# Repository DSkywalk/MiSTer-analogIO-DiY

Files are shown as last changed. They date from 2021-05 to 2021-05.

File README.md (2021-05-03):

# MiSTer-analogIO-DiY

The aim of this repository is to share boards that can be easily crafted at home (ex. Electric iron) for MiSTer FPGA enthusiasts. No SMD and trying to use almost one layer...

Of course, you can order these boards from OSHPark or any other PCB printing company, but that is not the main purpose of this repository.

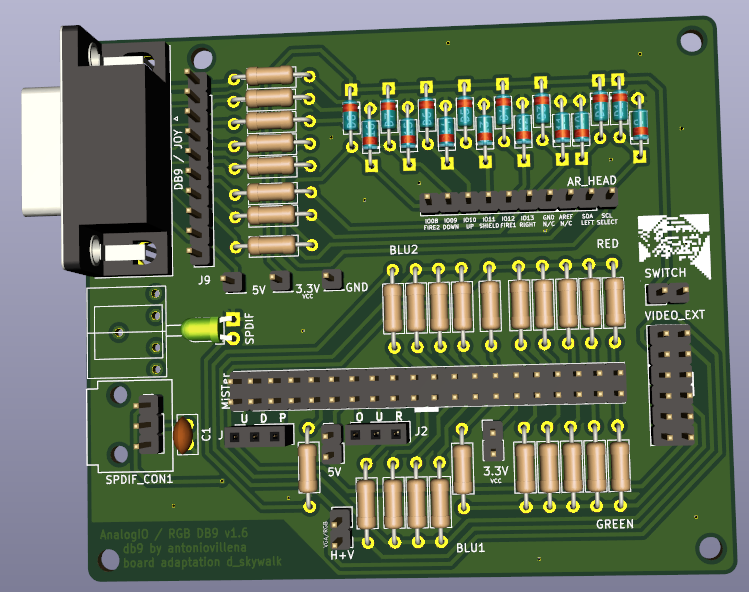
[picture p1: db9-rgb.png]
db9


This is my first project using Kicad, contributions are very welcome :+1:

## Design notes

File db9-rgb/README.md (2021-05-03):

# RGB + DB9 + MIDI

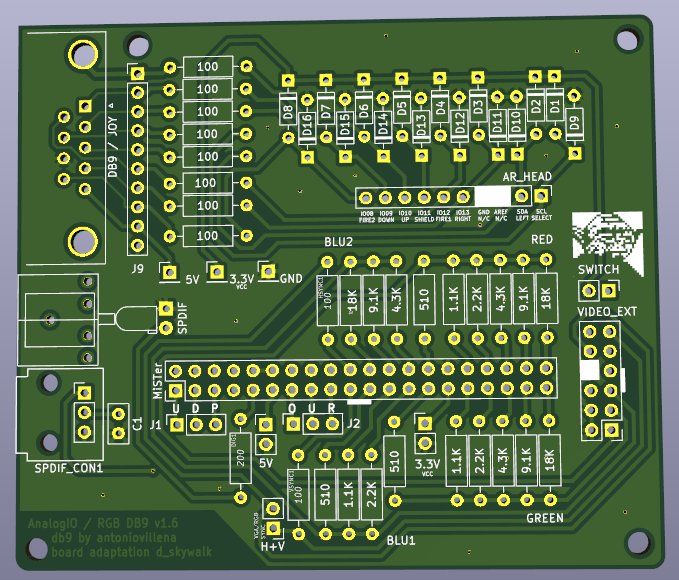
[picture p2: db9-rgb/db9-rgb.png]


### 1. Order PCB

#### Some PCB Manufactors
  * [OSH Park](https://oshpark.com/)
  * [PCBway](https://www.pcbway.com/)
  * [JLCPCB](https://jlcpcb.com/)

### 2. Order Components

This is a bill of materials to assemble an AnalogIO Board.

| Qty | Name | Component | Value | Reference Parts | Notes |
|---|---|---|:---:|---|---|
| 1 | CONNECTOR_... | Pin header 2.54mm 1x20 |  | [rs](https://uk.rs-online.com/web/p/pcb-headers/2518632/) [ebay-kit](https://www.ebay.co.uk/itm/SKY/192534020920) | some optional |
| 1 | MiSTer1 | Pin header 2.54mm 2x20 |  | [rs](https://uk.rs-online.com/web/p/pcb-headers/6703496/) [ebay](https://www.ebay.co.uk/itm/yavi/253239947055) | optional, you could use two 1x20 |
| 16 | D1...D16 | Schottky Diode - 30V 200mA | BAT42 / BAT42-TR | [rs](https://uk.rs-online.com/web/p/rectifier-diodes-schottky-diodes/5444758P/) | |
| 10 | HSYNC1, VSYNC1, DB9_1...8 | Resistor 1% / 5% 0.6W | 100 | [rs](https://uk.rs-online.com/web/p/through-hole-fixed-resistors/0148433/) [ebay-kit](https://www.ebay.es/itm/SKY/383379552017) | |
| 3 | RED_1, GRE_1, BLU_1 | Resistor 1% 0.6W | 510 | [rs](https://uk.rs-online.com/web/p/through-hole-fixed-resistors/0148433/) | |
| 3 | RED_2, GRE_2, BLU_2 | Resistor 1% 0.6W | 1.1K | [rs](https://uk.rs-online.com/web/p/through-hole-fixed-resistors/0148512/) | |
| 3 | RED_3, GRE_3, BLU_3 | Resistor 1% 0.6W | 2.2K | [rs](https://uk.rs-online.com/web/p/through-hole-fixed-resistors/6833449/) | |
| 3 | RED_4, GRE_4, BLU_4 | Resistor 1% 0.6W | 4.3K | [rs](https://uk.rs-online.com/web/p/through-hole-fixed-resistors/0148657/) | |
| 3 | RED_5, GRE_5, BLU_5 | Resistor 1% 0.6W | 9.1K | [rs](https://uk.rs-online.com/web/p/through-hole-fixed-resistors/0148720/) | |
| 3 | RED_6, GRE_6, BLU_6 | Resistor 1% 0.6W | 18K | [rs](https://uk.rs-online.com/web/p/through-hole-fixed-resistors/0148792/) | |

### 3. Optional Components
#### 3.1 SPDIF using LED

imagen

| Name | Component | Value | Reference Parts |
|---|---|:---:|---|
| SPDIF1 | LED 5mm | Red | [rs](https://uk.rs-online.com/web/p/products/2285988/) |
| DIG1 | Resistor 1% / 5% 0.6W | 200 | [rs](https://uk.rs-online.com/web/p/through-hole-fixed-resistors/0132321/) |
| DUMMY JACK | Socket Audio Jack Connector PCB 5Pin | 3F07 | [ali](https://www.aliexpress.com/item/32694891007.html) | 

#### 3.2 SPDIF using TOSLINK

imagen

| Name | Component | Value | Reference Parts |
|---|---|:---:|---|
| C1 | Capacitor (Ceramic) 0104 / 0105 | 1uF / 0.1uF | [rs](https://uk.rs-online.com/web/p/mlccs-multilayer-ceramic-capacitors/5381578/) |
| SPDIF_CON1 | Audio Fiber-Optic Terminal 03B | DLT-11E0 | [ali](https://www.aliexpress.com/item/4000333102343.html) |

#### 3.3 DB9 using PCB Socket

imagen

| Name | Component | Value | Reference Parts |
|---|---|:---:|---|
| DB9 | DSUB 90º |  | [rs](https://uk.rs-online.com/web/p/d-sub-connectors/2395855/) |

#### 3.4 DB9 using J9 Connector

imagen

| Name | Component | Value | Reference Parts |
|---|---|:---:|---|
| DB9 | DSUB |  | [rs](https://uk.rs-online.com/web/p/d-sub-connectors/5443749/) |

### 4. Other Options
#### 4.1 J1 Conector / EXTRA LED

These LEDs are completely optional, you can see them on the board itself, if you want to connect them to have them visible externally you will also need some 200ohm resistors. And connect them to GND like any other LED.

* U: LED USR
* U: LED DISK
* U: LED POWER

#### 4.2 J2 Conector / EXTRA BUTTONS

These buttons are completely optional, you can do the same operations using any controller. Connect them to GND.

* U: BTN OSD
* U: BTN USER
* U: BTN RESET

### 5 RGB
#### 5.1 VIDEO_EXT

This connector is commonly used for graphics with a VGA connector. Or you can solder your own.

imagen

| PIN | Name |
|---|---|
| 1 | RED |
| 3 | GREEN |
| 5 | BLUE |
| 2, 4 | GND |
| 10 | HSYNC (or H+V using JP1) |
| 11 | VSYNC |
| 8  | LOCKED/BLIND |
| 6,7,9,12 | NC |

#### 5.3 Useful Information

* HSYNC1 & VSYNC1 are attenuated with a 100-ohm resistance. You could use a variable resistor if you know your TV can be problematic or test other values.
* SWITCH PIN1: 3.3V You could use this connector as TV RGB SWITCH.
* SWITCH PIN2: 5V You could use this connector as TV AV SWITCH.

### 6 Notes
#### 6.1 JP1 / SYNC

Join this pin if you want to combine HSYNC and VSYNC or you prefer to have them separate, for PC-VGA separate them and for TV combine them.

#### 6.2 EX Heads

* JP1x01 5V, VCC (3.3V), GND: Ready for your usage.
* 5V1 JP_1x02: 5V + GND: Ready for your usage.
* 3.3V1 JP_1x02: 3.3V + GND: Ready for your usage.

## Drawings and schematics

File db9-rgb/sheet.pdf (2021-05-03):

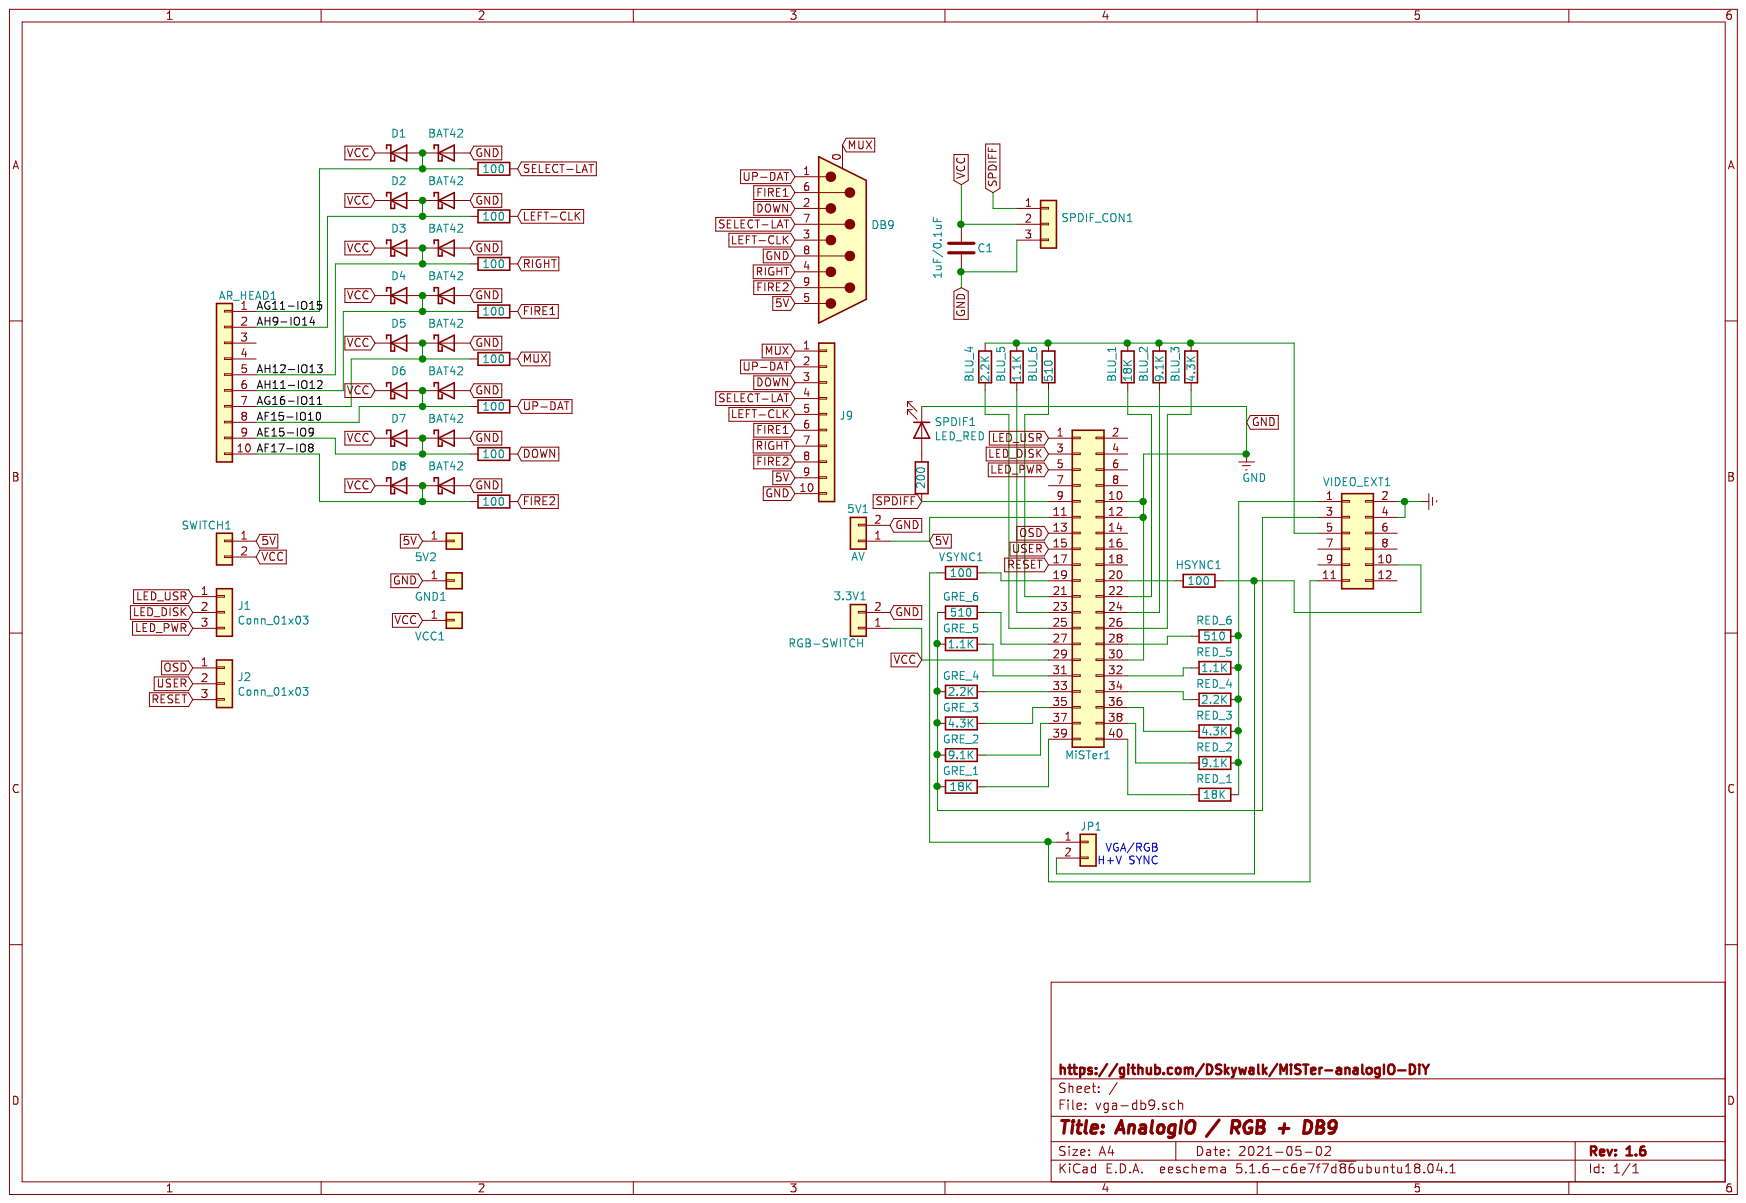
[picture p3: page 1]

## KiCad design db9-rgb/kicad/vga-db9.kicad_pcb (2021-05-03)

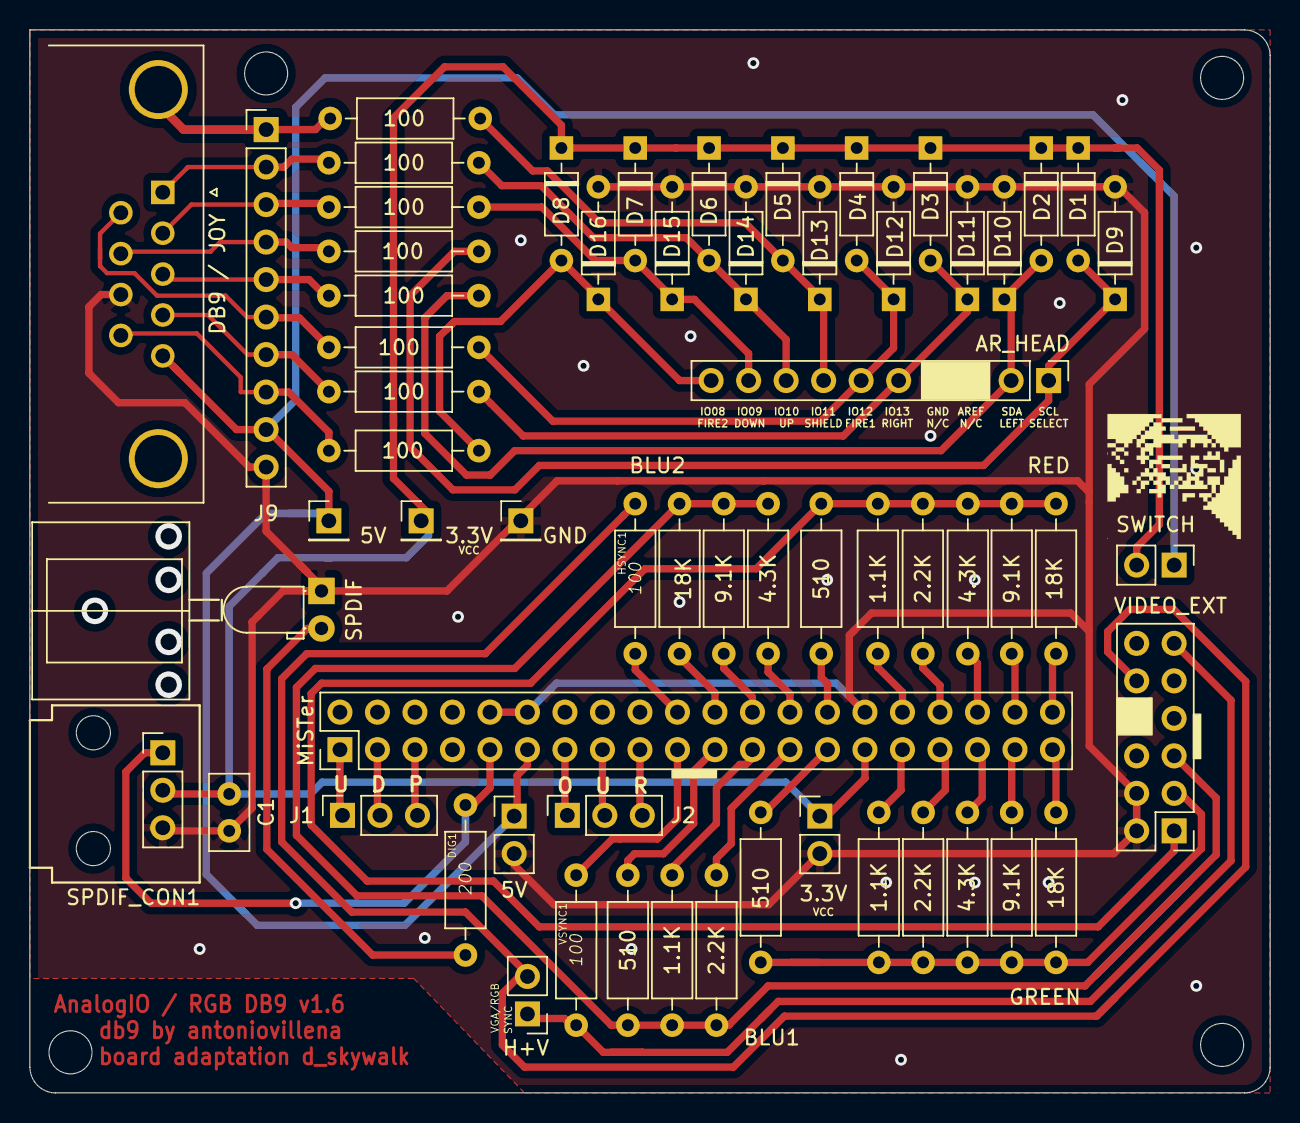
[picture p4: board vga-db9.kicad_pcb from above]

Board: 2 copper layers, 84.0 x 72.0 mm, 62 parts (0 on the bottom side), 52 nets.

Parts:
3.3V: 3V; PinHeader_1x01_P2.54mm_Vertical
3.3V#2: RGB-SWITCH; PinHeader_1x02_P2.54mm_Vertical
5V: 5V; PinHeader_1x01_P2.54mm_Vertical
5V#2: AV; PinHeader_1x02_P2.54mm_Vertical
AR_HEAD: 10; PinHeader_1x10_P2.54mm_Vertical
BLU_1: 18K; R_Axial_DIN0207_L6.3mm_D2.5mm_P10.16mm_Horizontal
BLU_2: 9.1K; R_Axial_DIN0207_L6.3mm_D2.5mm_P10.16mm_Horizontal
BLU_3: 4.3K; R_Axial_DIN0207_L6.3mm_D2.5mm_P10.16mm_Horizontal
BLU_4: 2.2K; R_Axial_DIN0207_L6.3mm_D2.5mm_P10.16mm_Horizontal
BLU_5: 1.1K; R_Axial_DIN0207_L6.3mm_D2.5mm_P10.16mm_Horizontal
BLU_6: 510; R_Axial_DIN0207_L6.3mm_D2.5mm_P10.16mm_Horizontal
C1: 1uF/0.1uF; C_Disc_D5.0mm_W2.5mm_P2.50mm
D1, D2, D3, D4, D5, D6, D7, D8, D9, D10, D11, D12, D13, D14, D15, D16: BAT42; D_DO-35_SOD27_P7.62mm_Horizontal
DB9 / JOY: DB9_Male; DSUB-9_Male_Horizontal_P2.77x2.84mm_EdgePinOffset4.94mm_Hou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
DB9_1, DB9_2, DB9_3, DB9_4, DB9_5, DB9_6, DB9_7, DB9_8: 100; R_Axial_DIN0207_L6.3mm_D2.5mm_P10.16mm_Horizontal
DIG1: 200; R_Axial_DIN0207_L6.3mm_D2.5mm_P10.16mm_Horizontal
GND: GND; PinHeader_1x01_P2.54mm_Vertical
GRE_1: 18K; R_Axial_DIN0207_L6.3mm_D2.5mm_P10.16mm_Horizontal
GRE_2: 9.1K; R_Axial_DIN0207_L6.3mm_D2.5mm_P10.16mm_Horizontal
GRE_3: 4.3K; R_Axial_DIN0207_L6.3mm_D2.5mm_P10.16mm_Horizontal
GRE_4: 2.2K; R_Axial_DIN0207_L6.3mm_D2.5mm_P10.16mm_Horizontal
GRE_5: 1.1K; R_Axial_DIN0207_L6.3mm_D2.5mm_P10.16mm_Horizontal
GRE_6: 510; R_Axial_DIN0207_L6.3mm_D2.5mm_P10.16mm_Horizontal
HSYNC1: 100; R_Axial_DIN0207_L6.3mm_D2.5mm_P10.16mm_Horizontal
J1, J2: Conn_01x03; PinSocket_1x03_P2.54mm_Vertical
J9: Conn_01x09; PinHeader_1x10_P2.54mm_Vertical
JP1: SYNC; PinHeader_1x02_P2.54mm_Vertical
MiSTer: Conn_02x20; PinHeader_2x20_P2.54mm_Vertical
RED_1: 18K; R_Axial_DIN0207_L6.3mm_D2.5mm_P10.16mm_Horizontal
RED_2: 9.1K; R_Axial_DIN0207_L6.3mm_D2.5mm_P10.16mm_Horizontal
RED_3: 4.3K; R_Axial_DIN0207_L6.3mm_D2.5mm_P10.16mm_Horizontal
RED_4: 2.2K; R_Axial_DIN0207_L6.3mm_D2.5mm_P10.16mm_Horizontal
RED_5: 1.1K; R_Axial_DIN0207_L6.3mm_D2.5mm_P10.16mm_Horizontal
RED_6: 510; R_Axial_DIN0207_L6.3mm_D2.5mm_P10.16mm_Horizontal
SPDIF: LED_RED; LED_D3.0mm_Horizontal_O1.27mm_Z2.0mm
SPDIF_CON1: Conn_alt; PinHeader_1x03_P2.54mm_Vertical
SWITCH: SYNC; PinHeader_1x02_P2.54mm_Vertical
VIDEO_EXT: Conn_02x06_Odd_Even; PinHeader_2x06_P2.54mm_Vertical
VSYNC1: 100; R_Axial_DIN0207_L6.3mm_D2.5mm_P10.16mm_Horizontal

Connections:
5V: 5V.1, 5V#2.1, DB9 / JOY.5, J9.9, MiSTer.11, SWITCH.1
/AE15-IO9: AR_HEAD.9, D7.2, D15.1, DB9_7.2
/AF15-IO10: AR_HEAD.8, D6.2, D14.1, DB9_6.2
/AF17-IO8: AR_HEAD.10, D8.2, D16.1, DB9_8.2
/AG11-IO15: AR_HEAD.1, D1.2, D9.1, DB9_1.2
/AG16-IO11: AR_HEAD.7, D5.2, D13.1, DB9_5.2
/AH9-IO14: AR_HEAD.2, D2.2, D10.1, DB9_2.2
/AH11-IO12: AR_HEAD.6, D4.2, D12.1, DB9_4.2
/AH12-IO13: AR_HEAD.5, D3.2, D11.1, DB9_3.2
DOWN: DB9 / JOY.2, DB9_7.1, J9.3
FIRE1: DB9 / JOY.6, DB9_4.1, J9.6
FIRE2: DB9 / JOY.9, DB9_8.1, J9.8
GND: 3.3V#2.2, 5V#2.2, C1.2, D9.2, D10.2, D11.2, D12.2, D13.2, D14.2, D15.2, D16.2, DB9 / JOY.8, GND.1, J9.10, MiSTer.10, MiSTer.12, MiSTer.30, SPDIF.1, SPDIF_CON1.3, VIDEO_EXT.2, VIDEO_EXT.4
LED_DISK: J1.2, MiSTer.3
LED_PWR: J1.3, MiSTer.5
LED_USR: J1.1, MiSTer.1
LEFT-CLK: DB9 / JOY.3, DB9_2.1, J9.5
MUX: DB9 / JOY.0, DB9_5.1, J9.1
unnamed: BLU_1.1, BLU_2.1, BLU_3.1, BLU_4.1, BLU_5.1, BLU_6.1, VIDEO_EXT.5
unnamed: BLU_1.2, MiSTer.22
unnamed: BLU_2.2, MiSTer.24
unnamed: BLU_3.2, MiSTer.26
unnamed: BLU_4.2, MiSTer.25
unnamed: BLU_5.2, MiSTer.23
unnamed: BLU_6.2, MiSTer.21
unnamed: DIG1.2, SPDIF.2
unnamed: GRE_1.1, MiSTer.39
unnamed: GRE_1.2, GRE_2.2, GRE_3.2, GRE_4.2, GRE_5.2, GRE_6.2, VIDEO_EXT.3
unnamed: GRE_2.1, MiSTer.37
unnamed: GRE_3.1, MiSTer.35
unnamed: GRE_4.1, MiSTer.33
unnamed: GRE_5.1, MiSTer.31
unnamed: GRE_6.1, MiSTer.27
unnamed: HSYNC1.1, MiSTer.20
unnamed: HSYNC1.2, JP1.2, VIDEO_EXT.10
unnamed: JP1.1, VIDEO_EXT.11, VSYNC1.2
unnamed: MiSTer.19, VSYNC1.1
unnamed: MiSTer.28, RED_6.1
unnamed: MiSTer.32, RED_5.1
unnamed: MiSTer.34, RED_4.1
unnamed: MiSTer.36, RED_3.1
unnamed: MiSTer.38, RED_2.1
unnamed: MiSTer.40, RED_1.1
unnamed: RED_1.2, RED_2.2, RED_3.2, RED_4.2, RED_5.2, RED_6.2, VIDEO_EXT.1
OSD: J2.1, MiSTer.13
RESET: J2.3, MiSTer.17
RIGHT: DB9 / JOY.4, DB9_3.1, J9.7
SELECT-LAT: DB9 / JOY.7, DB9_1.1, J9.4
SPDIFF: DIG1.1, MiSTer.9, SPDIF_CON1.1
UP-DAT: DB9 / JOY.1, DB9_6.1, J9.2
USER: J2.2, MiSTer.15
VCC: 3.3V.1, 3.3V#2.1, C1.1, D1.1, D2.1, D3.1, D4.1, D5.1, D6.1, D7.1, D8.1, MiSTer.29, SPDIF_CON1.2, SWITCH.2

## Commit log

2020-08-02 db9 - base files
    [vga-db9.kicad_pcb, vga-db9.sch]
2020-08-02 fix JP1 size
    [vga-db9.kicad_pcb, vga-db9.sch]
2020-08-02 update sync / new tv switch connector
    [vga-db9.kicad_pcb, vga-db9.sch]
2020-08-21 fixed resistors and spdif.
    [vga-db9.kicad_pcb, vga-db9.sch]
2021-05-02 upgraded to 1.6 - removed midi old, now using db9
    [vga-db9.kicad_pcb, vga-db9.sch]
2021-05-03 changed AR_HEAD order
    [vga-db9.kicad_pcb]
2021-05-03 fix size gfx
    [vga-db9.kicad_pcb]
